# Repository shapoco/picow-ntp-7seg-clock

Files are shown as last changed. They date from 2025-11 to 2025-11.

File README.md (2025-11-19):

# [WIP] Animated 7-segment Clock



NTP clock with animated 7-segment display.

## Components

|Part|Type|
|:--|:--|
|Board|RaspberryPi Pico2W|
|LED|anode common 7-segment LEDs (\*),<br>and same color chip LEDs|
|EEPROM|[AT24C32E](https://akizukidenshi.com/catalog/g/g115715/)|
|RTC|[RX-8025NB](https://akizukidenshi.com/catalog/g/g108585/)|
|Light Sensor|[NJL7502L](https://akizukidenshi.com/catalog/g/g102325/)|
|Switch|tactile switch|
|Battery|CR2032|
|Others|some resistors/capacitors/diodes|

(\*) I used `SS512UWWB`, which I bought at a local parts store, but I couldn't find its datasheet.

## Connection

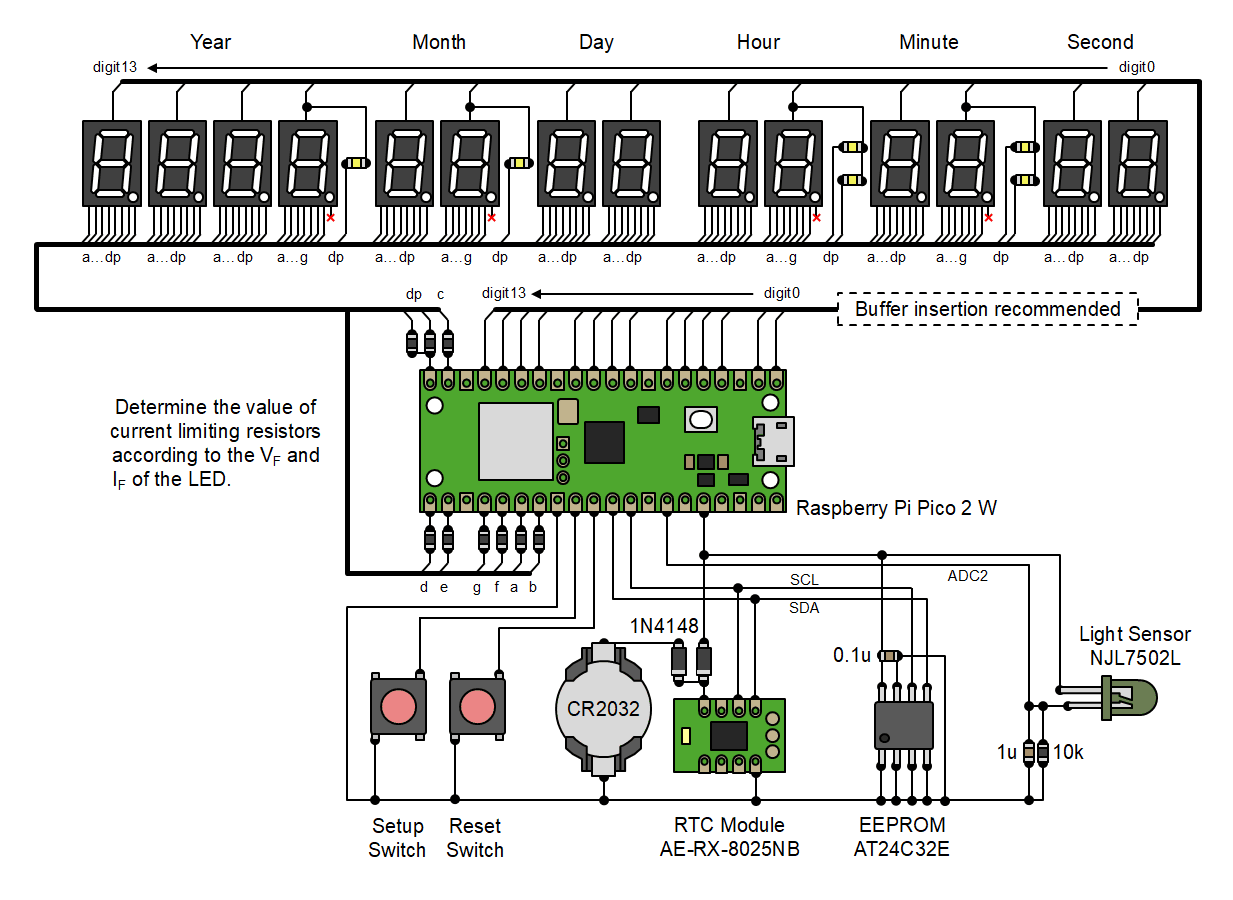
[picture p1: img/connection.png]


> [!NOTE]
> The value of the LED's current-limiting resistor should basically be determined based on V<sub>F</sub> and I<sub>F</sub>, but keep in mind that because it is a dynamic scanning method, the LED will appear much dimmer than if current were to flow continuously.

> [!WARNING]
> To avoid burning your Raspberry Pi Pico, I recommend inserting a buffer IC between the LED and the Pico (I'm lazy so I just wired them directly, but so far I haven't had any problems).

|Port|Connection|
|:--|:--|
|GP0|Digit\[0\]|
|GP1|Digit\[1\]|
|GP2|Digit\[2\]|
|GP3|Digit\[3\]|
|GP4|Digit\[4\]|
|GP5|Digit\[5\]|
|GP6|Digit\[6\]|
|GP7|Digit\[7\]|
|GP8|Digit\[8\]|
|GP9|Digit\[9\]|
|GP10|Digit\[10\]|
|GP11|Digit\[11\]|
|GP12|Digit\[12\]|
|GP13|Digit\[13\]|
|GP14|Segment 'c'|
|GP15|Segment 'dp'|
|GP16|Segment 'd'|
|GP17|Segment 'e'|
|GP18|Segment 'g'|
|GP19|Segment 'f'|
|GP20|Segment 'a'|
|GP21|Segment 'b'|
|GP22|Setup Switch|
|RUN|Reset Switch|
|GP26 (i2c1_sda)|EEPROM / RTC|
|GP27 (i2c1_scl)|EEPROM / RTC|
|GP28 (ADC2)|Light Sensor|

## Building Firmware

1. Install [Pico SDK](https://github.com/raspberrypi/pico-sdk) and set `PICO_SDK_PATH` environment variable.
2. Run `make` in `firmware/` directory.

    ```sh
    cd firmware
    make
    ```

3. `ntp_clock.uf2` generated in `firmware/bin/` directory.

## Setting Wi-Fi and NTP server

### via USB-Serial

1. Connect Raspberry Pi Pico to PC with USB cable.
2. Wait until the 7seg-display lights up.
3. Open a serial terminal with baudrate 115.2 kHz.
4. Press the setup switch ("ConFiG" will appear on the display).
5. Follow the prompts in the serial terminal to complete your settings.
6. The display will go blank for a few seconds, then show the time once the Wi-Fi connection and NTP synchronization are successful.

### via Light Sensor

1. Open the setup page from the link below and fill the form.

    - [Japan](https://shapoco.github.io/vlconfig/#form:%7Bt:Setup%20NTP%20Clock,e:%5B%7Bk:c,t:t,l:WiFi%20Country%20Code,v:JP,p:%28Worldwide%29%7D,%7Bk:s,t:t,l:SSID%7D,%7Bk:p,t:p,l:Password%7D,%7Bk:n,t:t,l:NTP%20Server,v:ntp.nict.jp,p:%28pool.ntp.org%29%7D,%7Bk:z,t:t,l:UTC%20Offset%20%28HHMM%29,v:%220900%22,p:%28UTC%29%7D%5D%7D)
    - [United States (EST)](https://shapoco.github.io/vlconfig/#form:%7Bt:Setup%20NTP%20Clock,e:%5B%7Bk:c,t:t,l:WiFi%20Country%20Code,v:US,p:%28Worldwide%29%7D,%7Bk:s,t:t,l:SSID%7D,%7Bk:p,t:p,l:Password%7D,%7Bk:n,t:t,l:NTP%20Server,p:%28pool.ntp.org%29%7D,%7Bk:z,t:t,l:UTC%20Offset%20%28HHMM%29,v:%22-0400%22,p:%28UTC%29%7D%5D%7D)

2. Press the setup switch ("ConFiG" will appear on the 7seg-display).
3. Place the light sensor over the lamp on the setup page and click the Submit button.
4. Wait until the light stops flashing.
5. The display will go blank for a few seconds, then show the time once the Wi-Fi connection and NTP synchronization are successful.

The received configuration data is stored in EEPROM.

> [!WARNING]
> The light signal and the data in the EEPROM are not encrypted, so be careful not to let someone spy on you watching the flashing or steal your clock.

Once configured, NTP synchronization will occur at a random time between 4:00 and 5:00 every morning.

For more information about the configuration interface, see the [VLConfig](https://github.com/shapoco/vlconfig) repository.

## Brightness Calibration

The clock learns changes in the room's brightness to determine the display brightness. The maximum brightness is learned within one minute after startup, and the minimum brightness is learned over time.

To calibrate the display brightness, follow these steps:

1. Place the clock in the desired location.
2. Turn on the power or press the reset switch.
3. Turn the room lights on for 30 seconds
4. Turn the room lights off or shield the light sensor for 30 seconds.

## Debug Mode

Press the reset switch while holding down the setup button to enter debug mode, in which trace information is displayed on the UART.

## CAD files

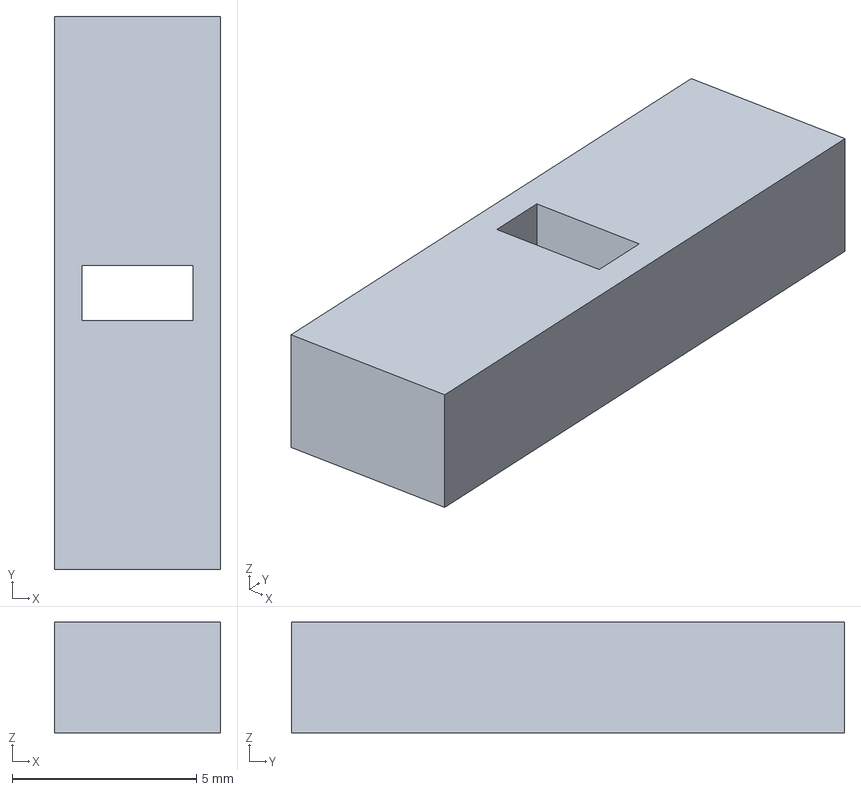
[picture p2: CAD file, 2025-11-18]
3dmodel/step/hyphen.step
4.50 x 15.0 x 3.00 mm

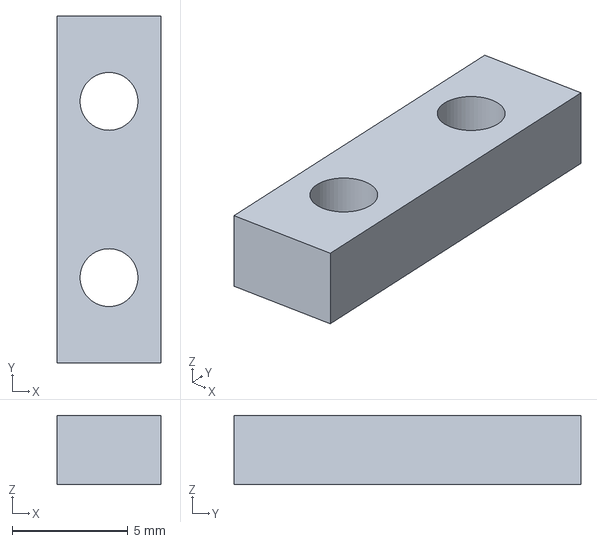
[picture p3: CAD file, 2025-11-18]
3dmodel/step/colon.step
4.50 x 15.0 x 3.00 mm

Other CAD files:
3dmodel/step/colon.stl
3dmodel/step/hyphen.stl

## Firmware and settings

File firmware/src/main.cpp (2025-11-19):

#include <cmath>
#include <cstdio>
#include <cstring>
#include <ctime>

#include <hardware/clocks.h>
#include <pico/stdlib.h>

#include <vlcfg/vlconfig.hpp>

#include "brightness.hpp"
#include "button.hpp"
#include "common.hpp"
#include "config.hpp"
#include "display.hpp"
#include "eeprom.hpp"
#include "ntp_client.hpp"
#include "rx8025nb.hpp"

using namespace ntpc;

static constexpr int SETUP_SW_PORT = 22;

Context ctx;

Button setup_button(SETUP_SW_PORT);

config::Config cfg;
rx8025nb::Driver rtc(I2C_HOST, SDA_PORT, SCL_PORT);

uint64_t t_next_button_update_ms = 0;
uint64_t t_next_display_update_ms = 0;

void i2c_reset();
void sync_from_rtc();
void sync_with_ntp();

int main() {
  set_sys_clock_khz(SYSTEM_CLOCK_HZ / 1000, true);
  sleep_ms(100);

  bool stdio_inited = stdio_init_all();
  sleep_ms(500);

  setup_button.init();
  debug_mode = stdio_inited && setup_button.is_down();
  if (debug_mode) {
    do {
      sleep_ms(1);
      setup_button.update(true);
    } while (setup_button.is_down());
    NTPC_VERBOSE("Verbose mode enabled.\r\n");
  }

  ctx.state = state_t::IDLE;
  ctx.origin_time_ms = 0;
  ctx.origin_tick_ms = to_ms_since_boot(get_absolute_time());
  ctx.next_sync_tick_ms = 0;
  ctx.last_error = result_t::SUCCESS;
  ctx.brightness = 256;

  display::init();
  brightness::init();

  i2c_reset();

  {
    rx8025nb::result_t res = rtc.init();
    if (res == rx8025nb::result_t::SUCCESS) {
      sync_from_rtc();
    } else {
      ctx.last_error = result_t::RTC_INIT_FAILED;
      NTPC_VERBOSE("RTC init failed.\r\n");
    }
  }

  ctx.origin_tick_ms = to_ms_since_boot(get_absolute_time());
  config::init(cfg);

  while (true) {
    const uint64_t tick_ms = to_ms_since_boot(get_absolute_time());
    bool pulse_1ms = (tick_ms >= t_next_button_update_ms);
    if (pulse_1ms) {
      t_next_button_update_ms = tick_ms + 1;
    }

    setup_button.update(pulse_1ms);

    if (setup_button.on_clicked()) {
      NTPC_VERBOSE("Setup button clicked\r\n");
    }

    switch (ctx.state) {
      case state_t::IDLE: {
        brightness::update(ctx, tick_ms);
        if (tick_ms >= ctx.next_sync_tick_ms) {
          sync_with_ntp();
        } else if (setup_button.on_clicked()) {
          NTPC_VERBOSE("Enter SETUP state\n");
          ctx.state = state_t::SETUP;
          config::start(cfg);
        }
      } break;

      case state_t::SETUP: {
        bool success = false;
        if (config::update(cfg, &success)) {
          if (success) {
            sync_with_ntp();
            ctx.state = state_t::IDLE;
          } else {
            ctx.state = state_t::VLCFG_ERROR;
          }
        } else if (setup_button.on_clicked()) {
          ctx.state = state_t::IDLE;
          NTPC_VERBOSE("Return to IDLE state\n");
        }
      } break;

      case state_t::VLCFG_ERROR:
        if (setup_button.on_clicked()) {
          ctx.state = state_t::IDLE;
          NTPC_VERBOSE("Return to IDLE state\n");
        }
        break;
    }

    if (tick_ms >= t_next_display_update_ms) {
      display::update_display(ctx);
      t_next_display_update_ms = tick_ms + 5;
    }
  }

  return 0;
}

void i2c_reset() {
  i2c_init(I2C_HOST ? i2c1 : i2c0, I2C_FREQ_HZ);
  gpio_init(SDA_PORT);
  gpio_init(SCL_PORT);
  gpio_pull_up(SDA_PORT);
  gpio_pull_up(SCL_PORT);
  gpio_set_function(SDA_PORT, GPIO_FUNC_I2C);
  gpio_set_function(SCL_PORT, GPIO_FUNC_I2C);
}

void sync_from_rtc() {
  uint64_t time_sec;
  rx8025nb::result_t res = rtc.get_time(&time_sec);
  if (res != rx8025nb::result_t::SUCCESS) {
    ctx.last_error = result_t::RTC_READ_FAILED;
    NTPC_VERBOSE("RTC time fetch failed: %d\n", static_cast<int>(res));
    return;
  }
  uint64_t time_ms = time_sec * 1000;

  ctx.origin_time_ms = time_ms;
  ctx.origin_tick_ms = to_ms_since_boot(get_absolute_time());
}

void sync_with_ntp() {
  display::turn_off();

  uint64_t time;
  auto res = ntp::get_time(cfg, &time);

  uint64_t tick_ms = to_ms_since_boot(get_absolute_time());
  ctx.last_try_time_ms = tick_ms;

  if (res != ntp::result_t::SUCCESS) {
    ctx.last_error = res;
    // If failed, retry in 10 minutes
    ctx.next_sync_tick_ms = tick_ms + 600 * 1000;
    NTPC_VERBOSE("NTP time fetch failed: %d\n", static_cast<int>(res));
    return;
  }

  // Add timezone offset
  int tz = atoi(cfg.timezone);
  int tz_hour = tz / 100;
  int tz_min = tz % 100;
  time += (uint64_t)(tz_hour * 3600 + tz_min * 60) * 1000;

  ctx.origin_time_ms = time;
  ctx.origin_tick_ms = tick_ms;
  ctx.last_error = result_t::SUCCESS;

  // Schedule the next sync between 4 AM and 5 AM the next day
  time_t now_sec = time / 1000;
  struct tm *t = gmtime(&now_sec);
  int time_sec = t->tm_hour * 3600 + t->tm_min * 60 + t->tm_sec;
  int expire_sec = (24 + 4) * 3600 + (rand() % 3600);
  int sec_to_next_sync = (expire_sec - time_sec) % (24 * 3600);
  ctx.next_sync_tick_ms = ctx.origin_tick_ms + sec_to_next_sync * 1000;

  {
    rx8025nb::result_t res = rtc.set_time(time / 1000);
    if (res != rx8025nb::result_t::SUCCESS) {
      ctx.last_error = result_t::RTC_WRITE_FAILED;
      NTPC_VERBOSE("RTC time set failed: %d\n", static_cast<int>(res));
    }
  }

  NTPC_VERBOSE("NTP time synchronized.\n");
}

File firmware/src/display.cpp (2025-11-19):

#include <hardware/dma.h>
#include <pico/stdlib.h>
#include <ctime>

#include "seg7_pwm_tx.pio.h"

#include "display.hpp"

namespace display {

using namespace ntpc;

static constexpr int DIGIT_PORTS[] = {0, 1, 2, 3,  4,  5,  6,
                                      7, 8, 9, 10, 11, 12, 13};
static constexpr int DIGIT_PORT_BASE = 0;

static constexpr int SEGMENT_PORTS[] = {20, 21, 14, 16, 17, 19, 18, 15};
static constexpr int SEGMENT_PORT_BASE = 14;

static constexpr int HYPHEN_COEFF = 255;
static constexpr int COLON_COEFF = 255;

static constexpr int NUM_DIGITS = 14;
static constexpr int NUM_SEGMENTS = 8;
static constexpr int PWM_PREC = 8;
static constexpr int PWM_PERIOD = 1 << PWM_PREC;

static constexpr int FADE_TIME_MS = 150;
static constexpr int FADE_DELAY_TABLE[] = {
    FADE_TIME_MS * 0 / 60,   // a
    FADE_TIME_MS * 10 / 60,  // b
    FADE_TIME_MS * 40 / 60,  // c
    FADE_TIME_MS * 60 / 60,  // d
    FADE_TIME_MS * 50 / 60,  // e
    FADE_TIME_MS * 20 / 60,  // f
    FADE_TIME_MS * 30 / 60,  // g
    FADE_TIME_MS * 55 / 60,  // dp
};
static constexpr int DIGIT_DELAY_MS = (1000 - FADE_TIME_MS * 3) / NUM_DIGITS;

static constexpr int FRAME_RATE = 120;
static constexpr int ANODE_SEL_HZ = FRAME_RATE * NUM_DIGITS;
static constexpr int ANODE_SEL_PERIOD_US = 1000000 / ANODE_SEL_HZ;
static constexpr int DMA_TX_HZ = ANODE_SEL_HZ * PWM_PERIOD * 11 / 10;
static constexpr int PIO_CLKDIV = ntpc::SYSTEM_CLOCK_HZ / DMA_TX_HZ;

static uint8_t segment_table[256] = {0};

static char digits0[NUM_DIGITS] = {0};
static char digits1[NUM_DIGITS] = {0};
static uint8_t dram0[NUM_DIGITS * NUM_SEGMENTS] = {0};
static uint8_t dram1[NUM_DIGITS * NUM_SEGMENTS] = {0};
static uint8_t dram2[NUM_DIGITS * NUM_SEGMENTS] = {0};
static uint8_t dma_buff[NUM_DIGITS * PWM_PERIOD] = {0};
static int digit_sel = 0;

static int transition_num_digits = 0;
static uint64_t transition_start_ms = 0;

static repeating_timer_t st_timer;
static int dma_chan;

static void render_clock(uint64_t time_ms);
static int get_blink_alpha(uint64_t time_ms);
static void dram_draw_string(const char *s, uint8_t alpha = 255,
                             int start_digit = NUM_DIGITS - 1);
static void dram_draw_char(char c, uint8_t alpha, int idig);
static void dram_draw_dp(int digit_index, uint8_t alpha = 255);
static void dram_clear(char c = ' ', uint8_t alpha = 255);
static void decode_segments(uint8_t alpha = 255);
static void update_dma_buff(uint16_t brightness);
static void print_digit(int index, int width, int value);

static bool repeating_timer_callback(repeating_timer_t *rt);

void init() {
  memset(segment_table, 0, sizeof(segment_table));
  segment_table[' '] = 0b00000000;
  segment_table['0'] = 0b00111111;
  segment_table['1'] = 0b00000110;
  segment_table['2'] = 0b01011011;
  segment_table['3'] = 0b01001111;
  segment_table['4'] = 0b01100110;
  segment_table['5'] = 0b01101101;
  segment_table['6'] = 0b01111101;
  segment_table['7'] = 0b00000111;
  segment_table['8'] = 0b01111111;
  segment_table['9'] = 0b01101111;
  segment_table['A'] = 0b01110111;
  segment_table['B'] = 0b01111100;
  segment_table['C'] = 0b00111001;
  segment_table['D'] = 0b01011110;
  segment_table['E'] = 0b01111001;
  segment_table['F'] = 0b01110001;
  segment_table['G'] = 0b00111101;
  segment_table['I'] = 0b00010000;
  segment_table['L'] = 0b00111000;
  segment_table['N'] = 0b01010100;
  segment_table['O'] = 0b01011100;
  segment_table['P'] = 0b01110011;
  segment_table['T'] = 0b01111000;
  segment_table['R'] = 0b01010000;
  segment_table['-'] = 0b01000000;

  for (int port : DIGIT_PORTS) {
    gpio_init(port);
    gpio_set_dir(port, GPIO_OUT);
    gpio_put(port, false);
    gpio_set_drive_strength(port, GPIO_DRIVE_STRENGTH_12MA);
  }
  memset(dma_buff, 0xFF, sizeof(dma_buff));

  turn_off();

  uint offset = pio_add_program(pio0, &seg7_pwm_tx_program);
  seg7_pwm_tx_program_init(pio0, 0, offset, SEGMENT_PORT_BASE, PIO_CLKDIV);

  dma_chan = dma_claim_unused_channel(true);
  dma_channel_config c = dma_channel_get_default_config(dma_chan);
  channel_config_set_transfer_data_size(&c, DMA_SIZE_8);
  channel_config_set_read_increment(&c, true);
  channel_config_set_dreq(&c, DREQ_PIO0_TX0);

  dma_channel_configure(dma_chan, &c, &pio0_hw->txf[0], NULL, PWM_PERIOD,
                        false);

  add_repeating_timer_us(-ANODE_SEL_PERIOD_US, repeating_timer_callback, NULL,
                         &st_timer);
}

void update_display(Context &ctx) {
  uint64_t tick_ms = to_ms_since_boot(get_absolute_time());
  const uint64_t time_ms = ctx.origin_time_ms + (tick_ms - ctx.origin_tick_ms);

  if (ctx.state == state_t::IDLE) {
    uint64_t elapsed_ms = tick_ms - ctx.last_try_time_ms;
    if (ctx.last_error != result_t::SUCCESS && elapsed_ms < 5000) {
      // エラー表示
      dram_clear();
      char msg[16];
      int err = static_cast<int>(ctx.last_error);
      snprintf(msg, sizeof(msg), "NTPERR%02X", err);
      dram_draw_string(msg);
    } else if (ctx.origin_time_ms == 0) {
      // 時刻未設定
      int alpha = get_blink_alpha(time_ms);
      dram_clear('-', alpha);
      dram_draw_dp(10, HYPHEN_COEFF * alpha / 256);
      dram_draw_dp(8, HYPHEN_COEFF * alpha / 256);
      dram_draw_dp(4, COLON_COEFF * alpha / 256);
      dram_draw_dp(2, COLON_COEFF * alpha / 256);
    } else {
      // 通常時刻表示
      render_clock(time_ms);
    }
  } else if (ctx.state == state_t::SETUP) {
    dram_clear();
    if (config::is_receiving()) {
      const char *s = "LOADING";
      for (int i = 0; s[i] != '\0'; i++) {
        int pos = NUM_DIGITS - 1 - i;
        uint8_t alpha = get_blink_alpha(time_ms + pos * 100);
        dram_draw_char(s[i], alpha, pos);
      }
    } else {
      dram_draw_string("CONFIG", get_blink_alpha(time_ms));
    }
  } else if (ctx.state == state_t::VLCFG_ERROR) {
    dram_clear();
    char msg[16];
    int err = static_cast<int>(config::last_vlcfg_error());
    snprintf(msg, sizeof(msg), "CFGERR%02X", err);
    dram_draw_string(msg);
    dram_draw_dp(6, config::last_bit() ? 255 : 0);
  }

  if (tick_ms - ctx.origin_tick_ms > 25 * 3600 * 1000) {
    // 前回の同期から25時間以上経っていたら右端のドットを点滅
    uint8_t alpha = (tick_ms % 1000 < 500) ? 255 : 0;
    dram_draw_dp(0, alpha);
  }

  uint16_t brightness = 256;
  if (ctx.state == state_t::IDLE) {
    brightness = ctx.brightness;
  }
  update_dma_buff(brightness);
}

void turn_off() {
  memset(digits0, 0, sizeof(digits0));
  memset(digits1, 0, sizeof(digits1));
  transition_num_digits = 0;

  memset(dram0, 0, sizeof(dram0));
  memset(dram1, 0, sizeof(dram1));
  memset(dram2, 0, sizeof(dram2));
  memset(dma_buff, 0xFF, sizeof(dma_buff));
}
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
